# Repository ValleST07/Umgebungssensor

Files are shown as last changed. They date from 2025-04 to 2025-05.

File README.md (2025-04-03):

> [!IMPORTANT]
> Um ein Programm auf den ESP32-C3 zu flashen, muss in den bootloader-Mode gewechselt werden!\
> [Hier](https://www.edgemicrotech.com/esp32-c3-super-mini-arduino-ide-quick-start-guide/) ein einfaches Tutorial um den ESP32-C3 SuperMini richtig zu flashen.

# Umgebungssensor Projekt
## ESP32-C3 SuperMini
### Pin Out zum Board
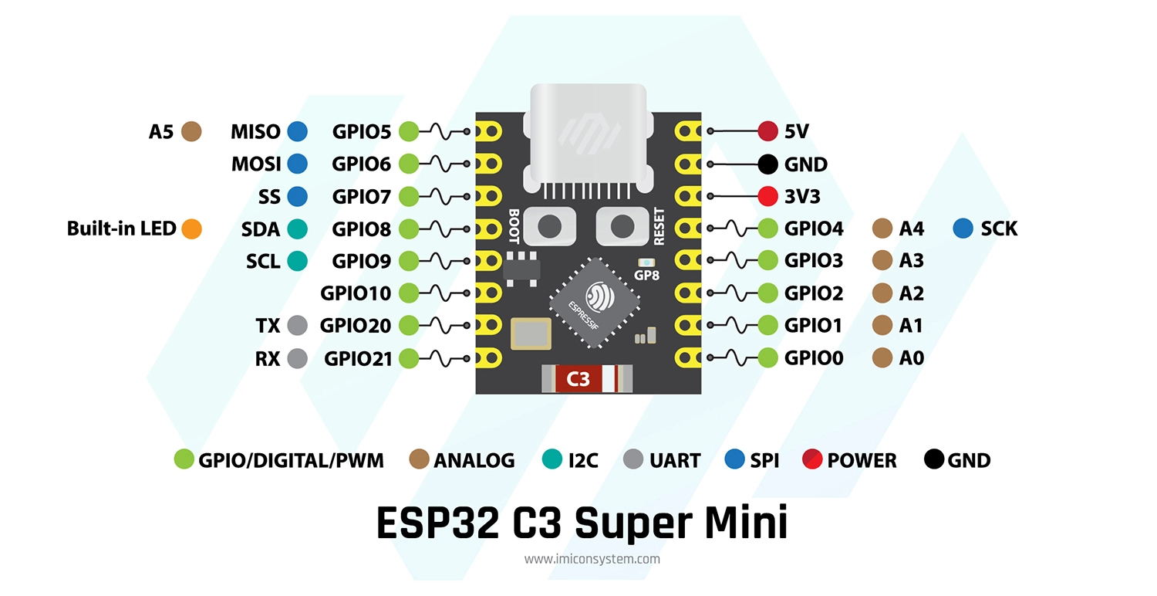
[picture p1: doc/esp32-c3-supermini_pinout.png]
ESP32-C3 SuperMini Pin Out

Wichtige PINs für das Projekt:
- GPIO8: I²C SDA
- GPIO9: I²C SCK
- GND: Ground Potential
- 3V3: 3,3V Potential für BME280 und SH1106
### Vorbereitung zur Programmierung ([ArduinoIDE](https://www.arduino.cc/en/software/))
- Wenn du bereits ESP32 programmiert hast, kannst du diesen Punkt überspringen!
    - Hier bitte noch den passenden Treiber herrunterladen: [CP210x USB to UART Bridge VCP Drivers](https://www.silabs.com/developer-tools/usb-to-uart-bridge-vcp-drivers?tab=downloads)
    - Im Board-Manager die ESP32 Boards installieren oder folgenden Link anführen: `https://dl.espressif.com/dl/package_esp32_index.json`
- Als Board zum Programmiern: ESP32C3 Dev Module

> [!NOTE]
> In der IDE in der Menubar unter "Tools" → "USB CDC on Boot" → "Enable" einstellen. Somit sollte später keine Probleme auftreten, wenn du die Serielleschnittstelle benutzen möchtest.

Somit sollten alle Vorbereitung zur Programmierung getroffen worden sein.

## Verdrahtung und PCB
### Verdrahtung
### PCB

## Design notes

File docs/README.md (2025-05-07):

![Made at CCA](https://img.shields.io/badge/Made_at-CCA-gray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)


> [!IMPORTANT]
> Um ein Programm auf den ESP32-C3 zu flashen, muss in den bootloader-Mode gewechselt werden!\
> [Hier](https://www.edgemicrotech.com/esp32-c3-super-mini-arduino-ide-quick-start-guide/) ein einfaches Tutorial um den ESP32-C3 SuperMini richtig zu flashen.

# Umgebungssensor Projekt
## ESP32-C3 SuperMini
### Pin Out zum Board
ESP32-C3 SuperMini Pin Out
Wichtige PINs für das Projekt:
- GPIO8: I²C SDA
- GPIO9: I²C SCK
- GND: Ground Potential
- 3V3: 3,3V Potential für BME280 und SH1106
### Vorbereitung zur Programmierung ([ArduinoIDE](https://www.arduino.cc/en/software/))
- Wenn du bereits ESP32 programmiert hast, kannst du diesen Punkt überspringen!
    - Hier bitte noch den passenden Treiber herrunterladen: [CP210x USB to UART Bridge VCP Drivers](https://www.silabs.com/developer-tools/usb-to-uart-bridge-vcp-drivers?tab=downloads)
    - Im Board-Manager die ESP32 Boards installieren oder folgenden Link anführen: `https://dl.espressif.com/dl/package_esp32_index.json`
- Als Board zum Programmiern: ESP32C3 Dev Module

> [!NOTE]
> In der IDE in der Menubar unter "Tools" → "USB CDC on Boot" → "Enable" einstellen. Somit sollte später keine Probleme auftreten, wenn du die Serielleschnittstelle benutzen möchtest.

Somit sollten alle Vorbereitung zur Programmierung getroffen worden sein.
## OLED-Display: SH1106
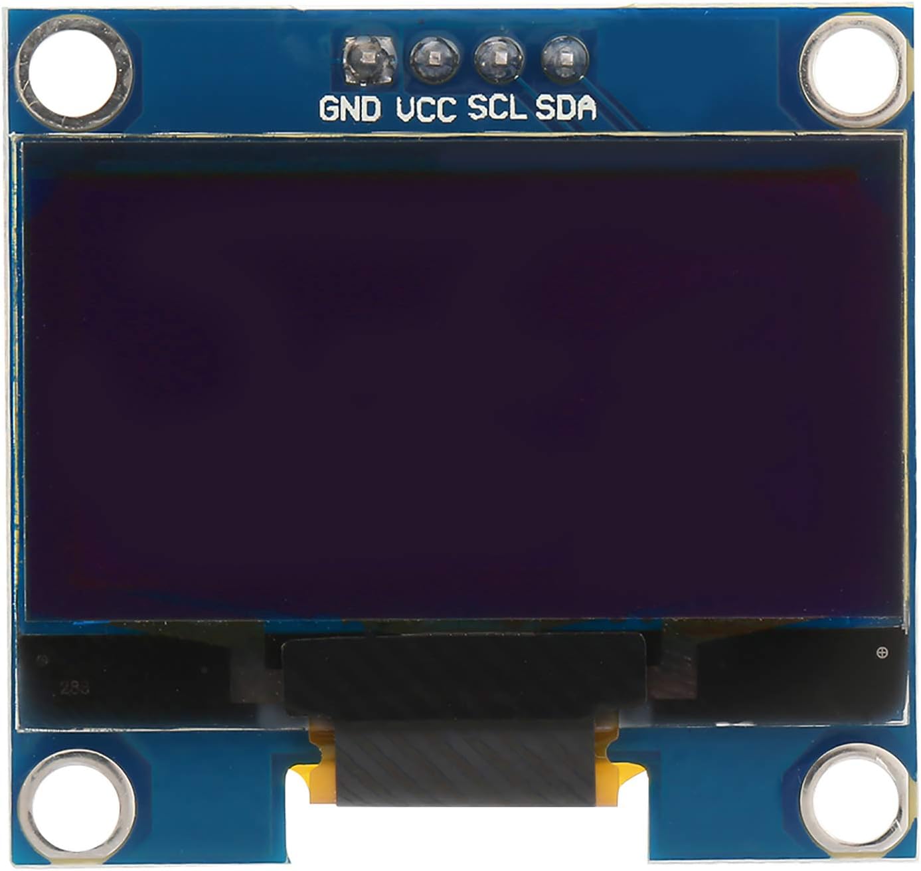
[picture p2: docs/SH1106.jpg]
 \
Das OLED Display kann über das Bussystem **I²C** angesteuert werden. Es aggiert dabei als Slave. Mithilfe der Library U8g2 wird die Anzeige angesteuert. Laut Datasheet kann es mit 3,3V oder 5V Versorgungsspannung bedient werden.<br/> <br/>
Weitere interessante Fakten:
- Dimensionen (LxBxT): 36 mm x 34 mm x 3 mm
- Auflösung: 128px x 64px
- Stromverbrauch: <11mA
- Displaygröße: 1,3 inch
- Displayfarbe: Monochrom (weiß)
## Sensor: BME280
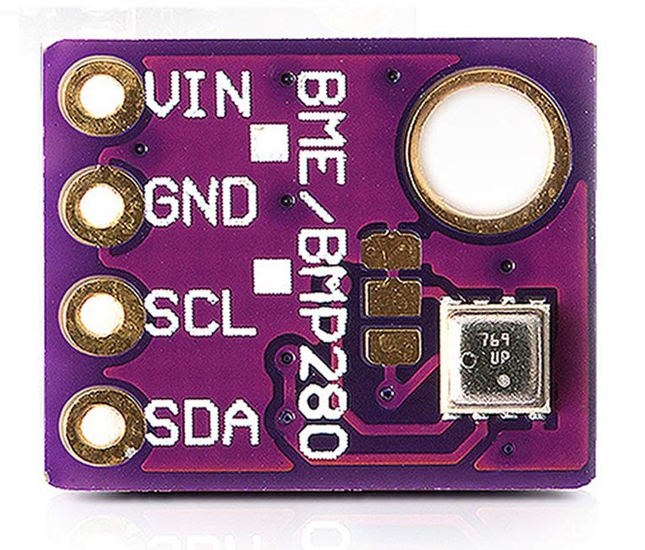
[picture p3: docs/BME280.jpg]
 \
Auch der Sensor wird via **I²C** angesteuert und befindet sich dabei ebenfalls im Slave-Modus. Die Softwareansteuerung erfolgte über die Adafruit BME280 Library die noch folgende Abhängigkeit mit der Adafruit Unified Sensor Driver hat. Auch dieses Modul kann mit 3,3V oder auch 5V betrieben werden, wie aus dem Datenblatt zu entnehemen ist.<br/> <br/>
Weitere interessante Fakten:
- Temperature: -40°C bis 85 °C;  Genauigkeit: ±1.0°C
- Luftdruck: 300 hPa bis 1100 hPa; Genauigkeit: ±1hPa
- Luftfeuchtigkeit: 0% bis 100%; Genauigkeit: ±3%
- Stromverbrauch: <1mA
## Verdrahtung und PCB
### Verdrahtung
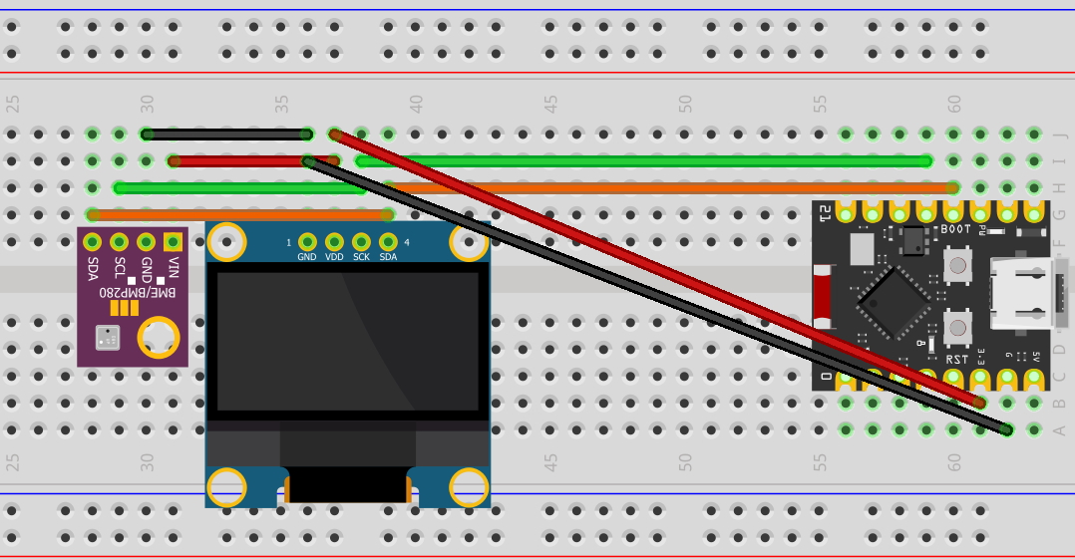
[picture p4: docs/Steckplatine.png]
Steckbrettaufbau

### PCB
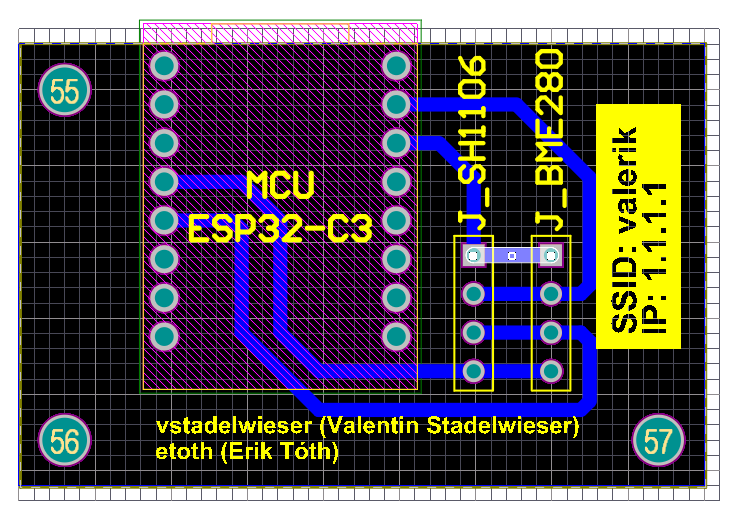
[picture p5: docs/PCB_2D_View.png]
2D-View: PCB

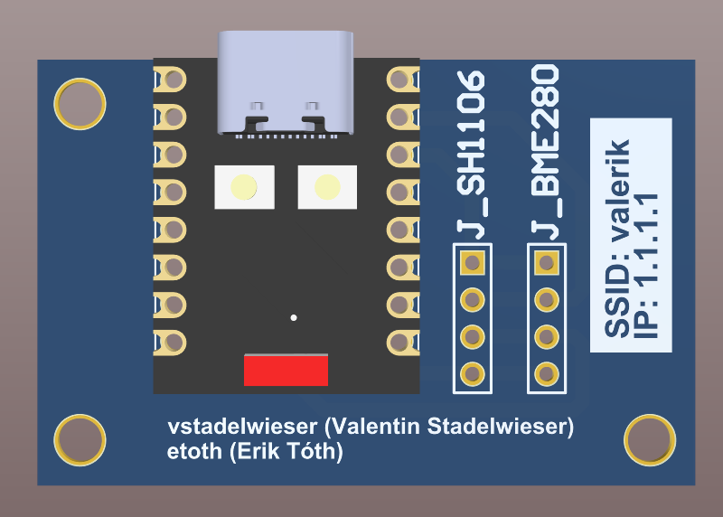
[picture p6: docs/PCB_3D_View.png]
3D-View: PCB


## Gehäuse
In Autodesk Inventor wurde ein simples und kompaktes Gehäusedesign vorgenommen.
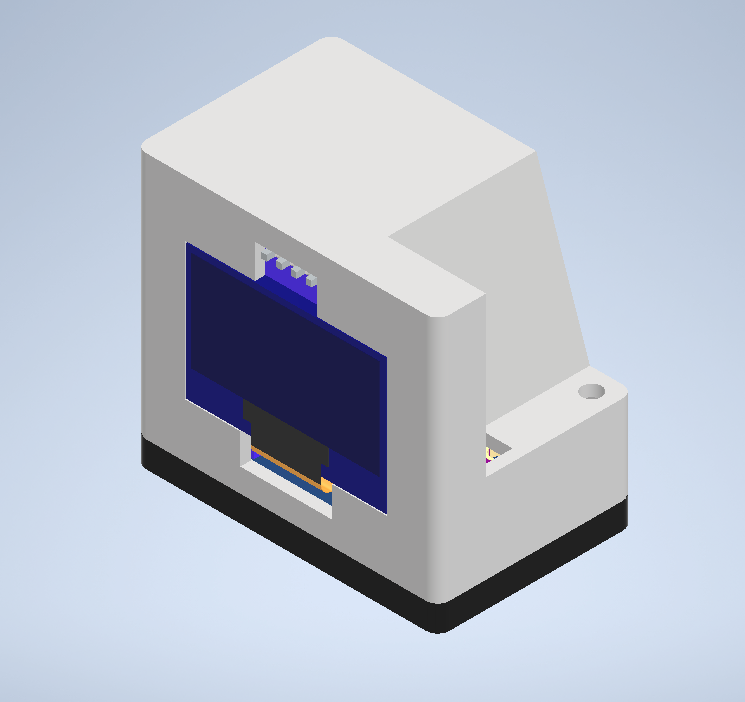
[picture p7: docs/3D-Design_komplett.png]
3D-Design: Komplett

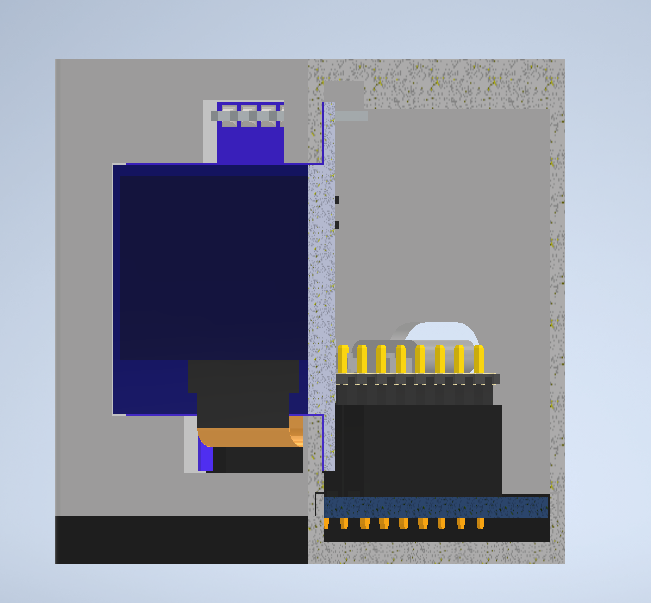
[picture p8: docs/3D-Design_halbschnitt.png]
3D-Design: Halbschnitt


## Website
### Funktionen
- Auswählbarer Internetmodus (Acces Point oder Standalone)
- OTA Update
- Graphische Aufbereitung mit Chart (nur im Standalone Mode)
- Display (Daten und Internet Einstellungen)
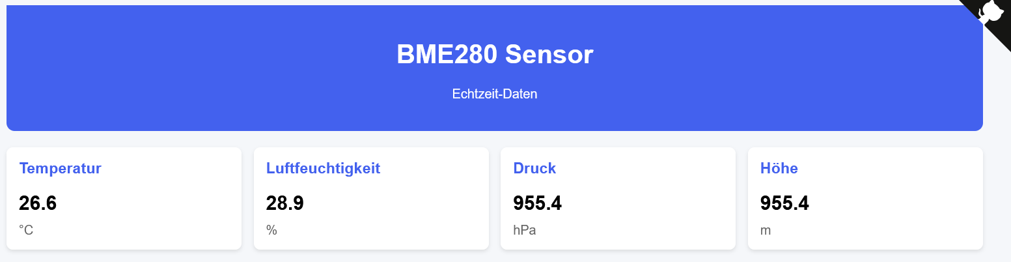
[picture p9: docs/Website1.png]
Website

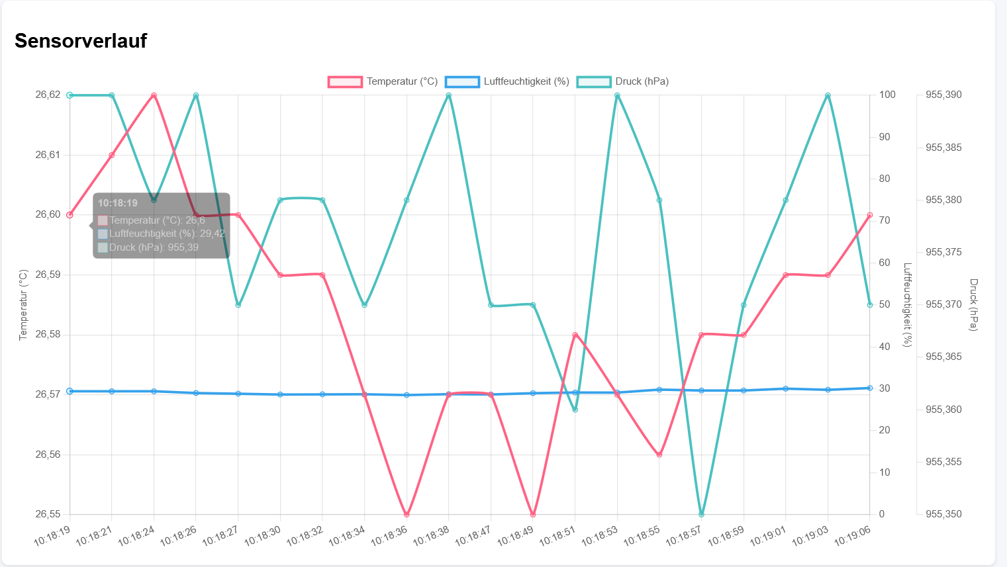
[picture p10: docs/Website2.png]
Website

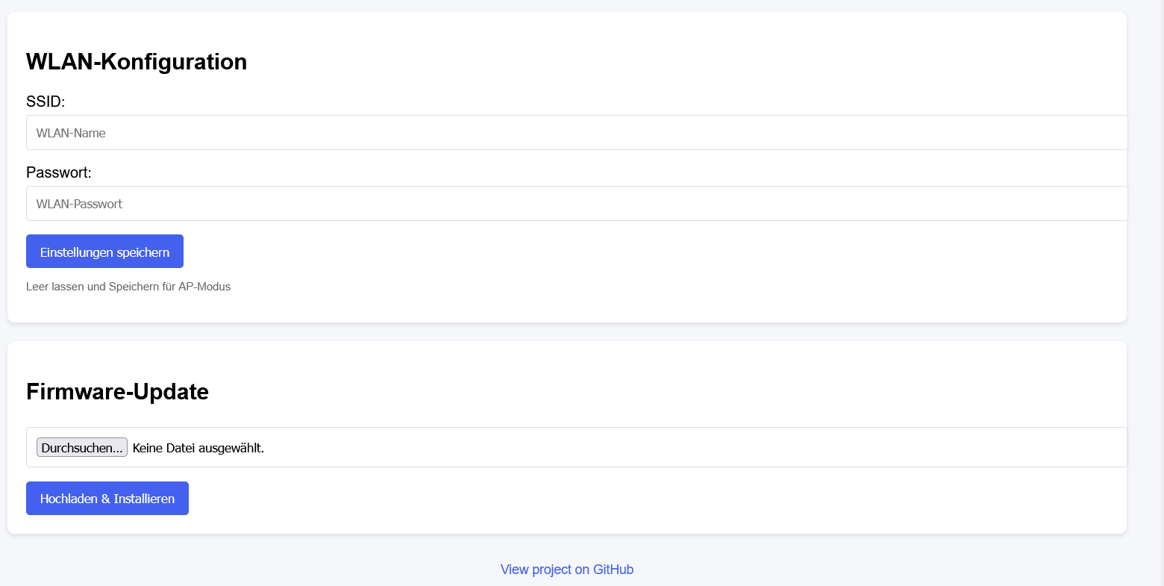
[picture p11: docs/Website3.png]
Website


## Fertig
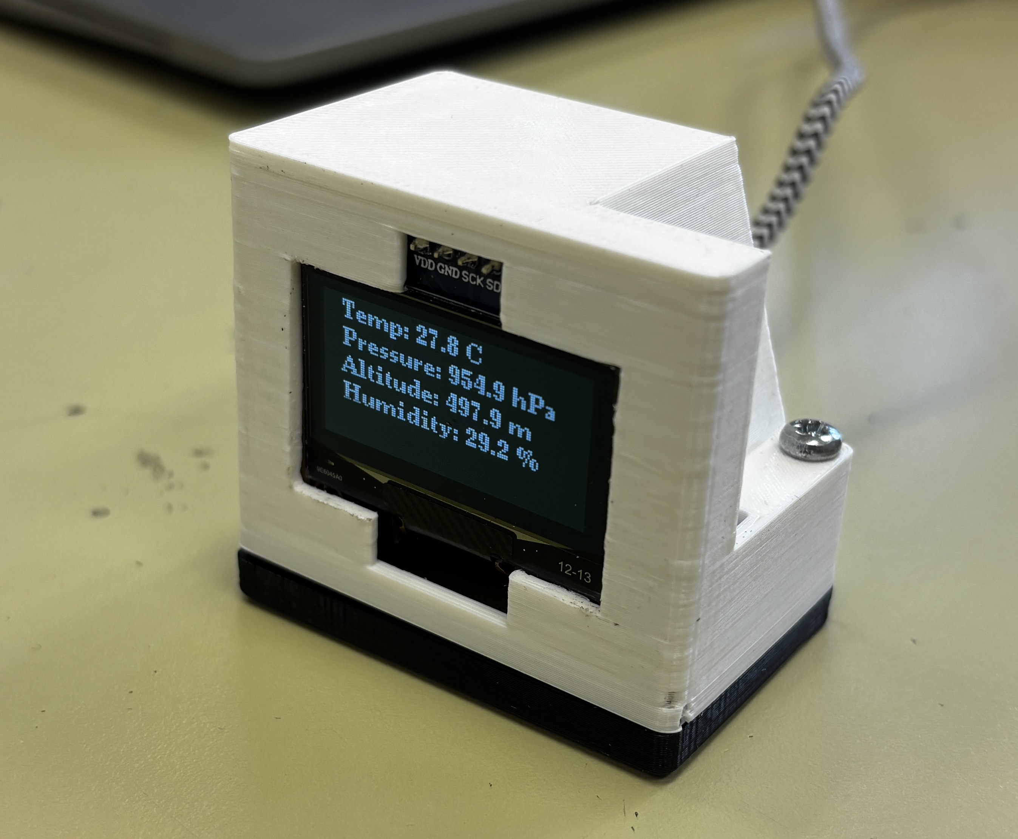
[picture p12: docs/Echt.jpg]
Echt


## Arbeitsteilung
Hardware & Gehäuse: Erik Tóth \
Software: Valentin Stadelwieser

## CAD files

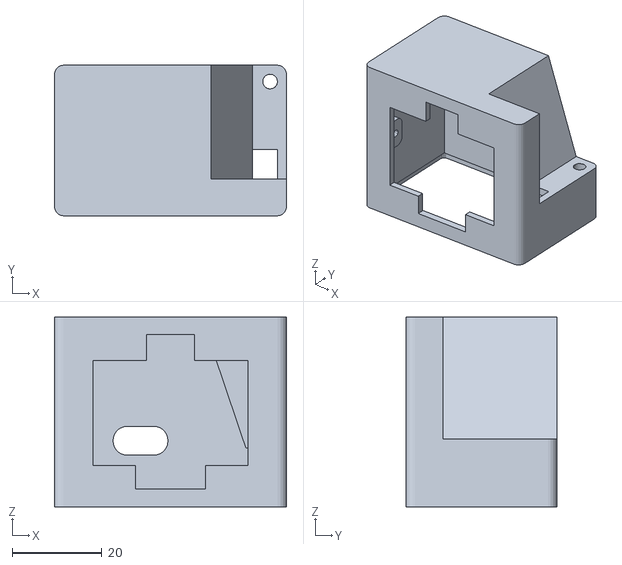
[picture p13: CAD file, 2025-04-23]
Fertigung/Gehaeuse_oben.stl
51.6 x 33.5 x 42.2

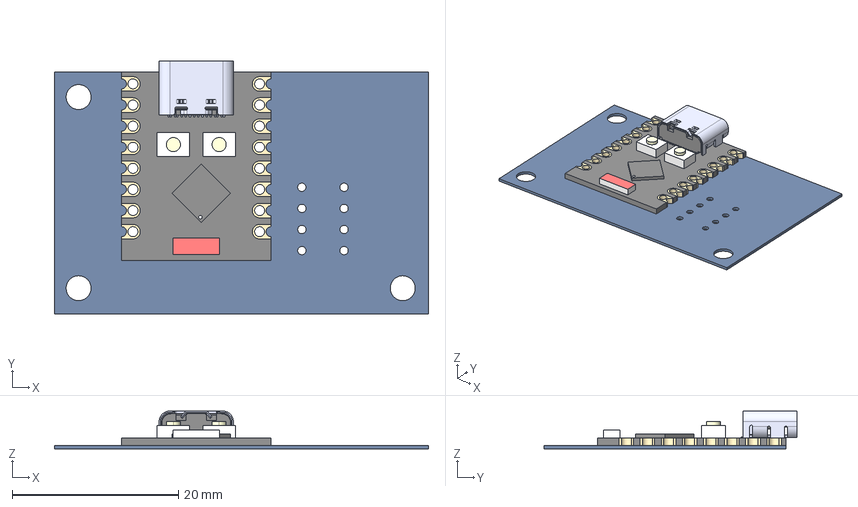
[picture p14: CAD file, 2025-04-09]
Umgebungssensor_PCB/Umgebungssensor_PCB.step
45.0 x 30.4 x 4.57 mm
Board c3mini
USB C
components (other)^ESP32-C3 SuperMini

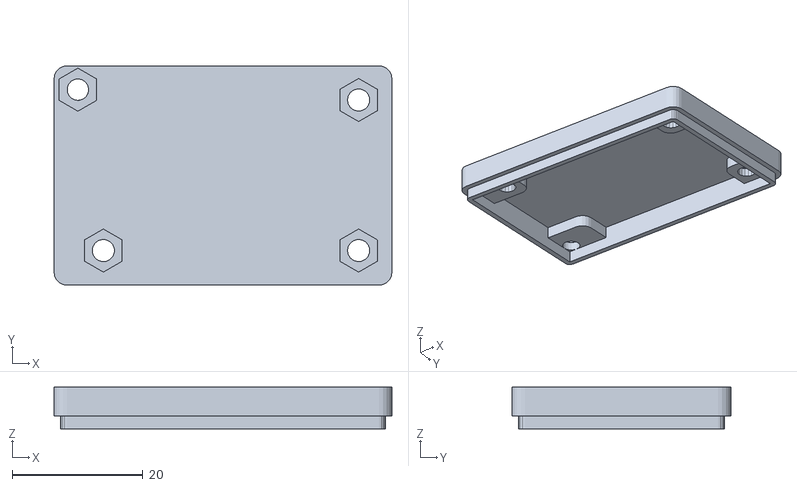
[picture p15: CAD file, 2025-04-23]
Fertigung/Gehaeuse_unten.stl
51.6 x 33.5 x 6.41

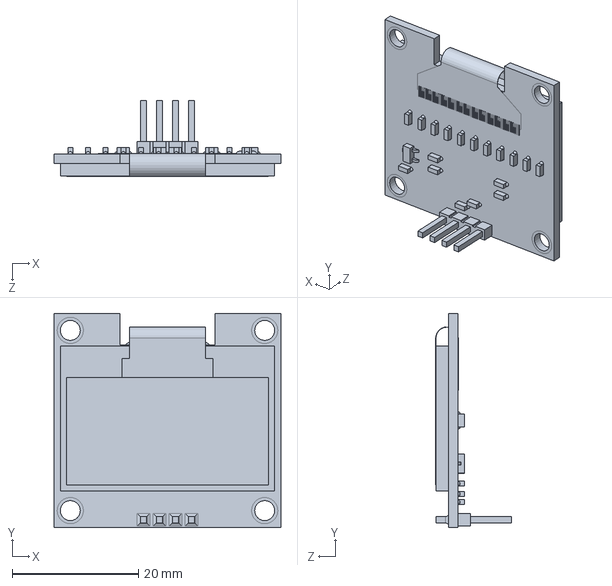
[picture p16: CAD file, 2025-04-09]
Gehaeuse_Umgebungssensor/Oled SH1106.SLDPRT
36.0 x 34.0 x 12.1 mm

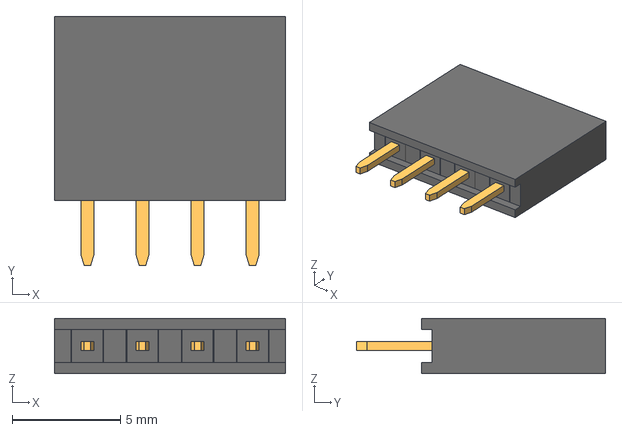
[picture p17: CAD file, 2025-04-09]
Gehaeuse_Umgebungssensor/zl262-4s_p2-54_l10-6_w2-54_h8-5.stp
10.7 x 11.5 x 2.54 mm

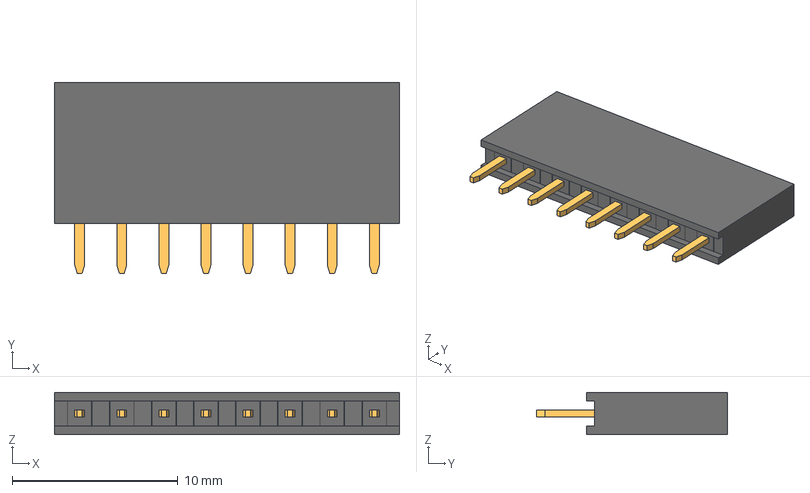
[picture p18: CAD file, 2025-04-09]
Gehaeuse_Umgebungssensor/zl262-8s_p2-54_l20-8_w2-54_h8-5.stp
20.8 x 11.5 x 2.54 mm

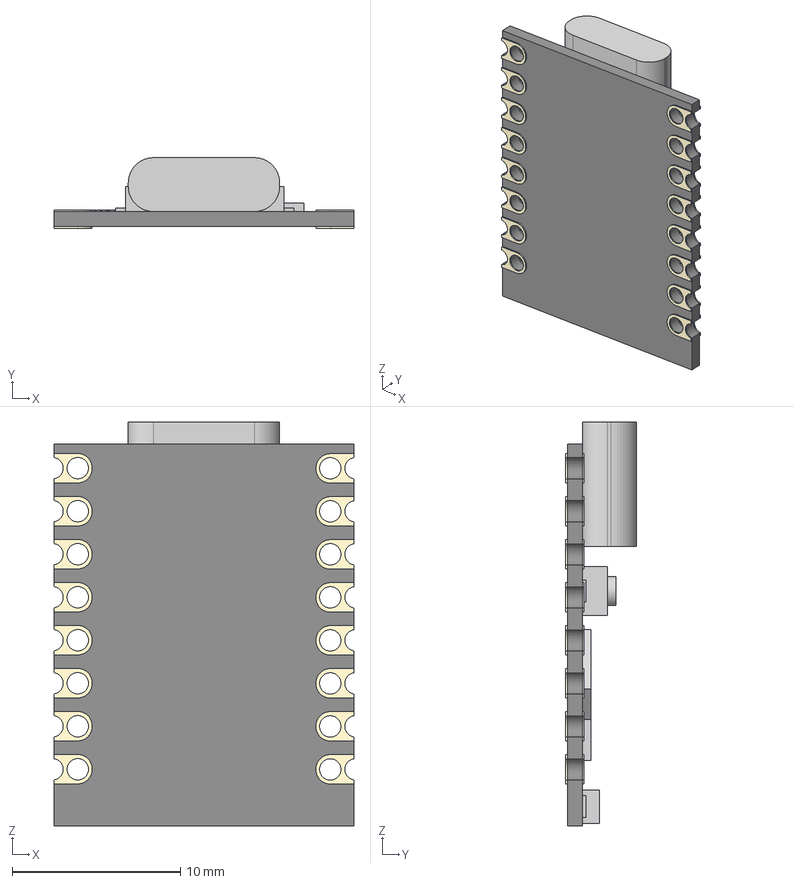
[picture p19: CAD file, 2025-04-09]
Gehaeuse_Umgebungssensor/ESP32-C3 supermini v5.step
17.8 x 4.20 x 24.0 mm

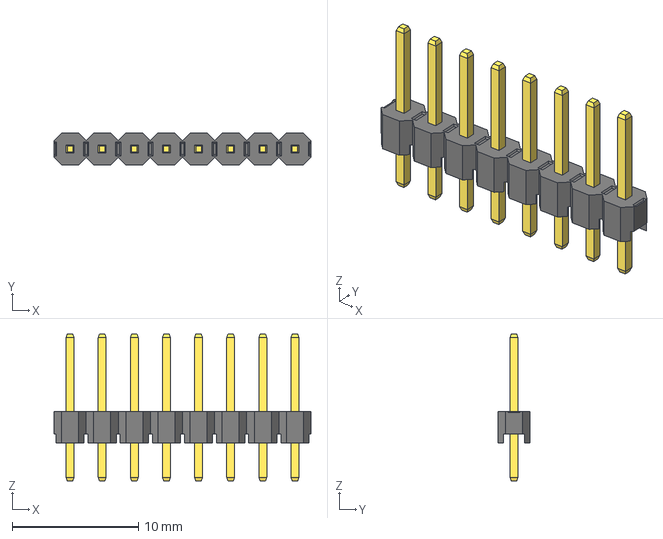
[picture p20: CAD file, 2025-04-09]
Gehaeuse_Umgebungssensor/PLS-8.step
20.3 x 2.54 x 11.6 mm

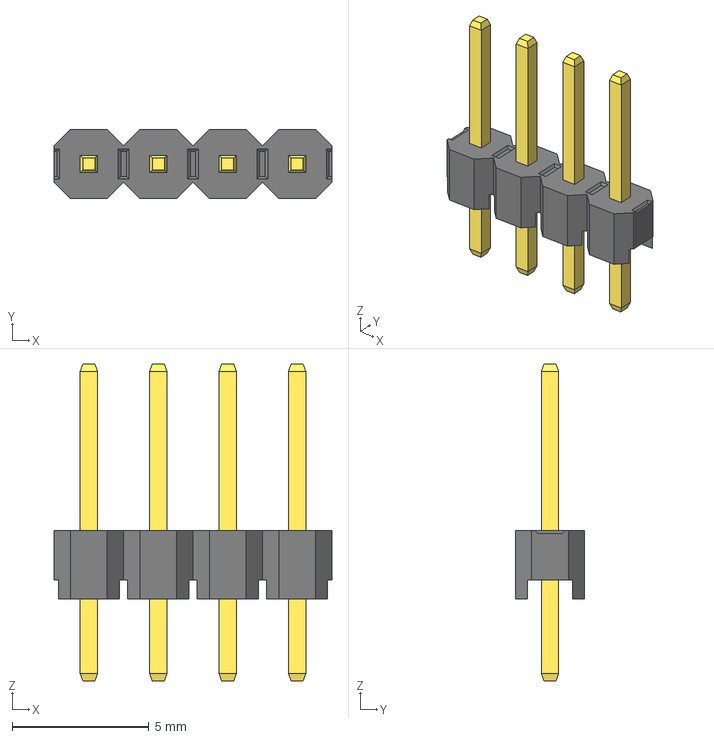
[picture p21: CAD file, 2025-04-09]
Gehaeuse_Umgebungssensor/PLS-4.step
10.2 x 2.54 x 11.6 mm

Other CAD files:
Gehaeuse_Umgebungssensor/Umgebungssensor_PCB.stl
Gehaeuse_Umgebungssensor/ESP32-C3 supermini v5/ESP32-C3 supermini v5.ipt
Gehaeuse_Umgebungssensor/GY-BME280/GY-BME280.ipt
Gehaeuse_Umgebungssensor/Gehaeuse_oben.ipt
Gehaeuse_Umgebungssensor/Gehaeuse_unten.ipt
Gehaeuse_Umgebungssensor/OldVersions/Gehaeuse_oben.0003.ipt
Gehaeuse_Umgebungssensor/OldVersions/Gehaeuse_unten.0003.ipt
Gehaeuse_Umgebungssensor/OldVersions/main.0006.iam
Gehaeuse_Umgebungssensor/Oled SH1106/Oled SH1106.ipt
Gehaeuse_Umgebungssensor/PLS-4/PLS-4.ipt
Gehaeuse_Umgebungssensor/PLS-8/PLS-8.ipt
Gehaeuse_Umgebungssensor/Umgebungssensor_PCB/OldVersions/Umgebungssensor_PCB.0002.ipt
Gehaeuse_Umgebungssensor/Umgebungssensor_PCB/Umgebungssensor_PCB.ipt
Gehaeuse_Umgebungssensor/main.iam
Gehaeuse_Umgebungssensor/zl262-4s_p2-54_l10-6_w2-54_h8-5/zl262-4s_p2-54_l10-6_w2-54_h8-5.ipt
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

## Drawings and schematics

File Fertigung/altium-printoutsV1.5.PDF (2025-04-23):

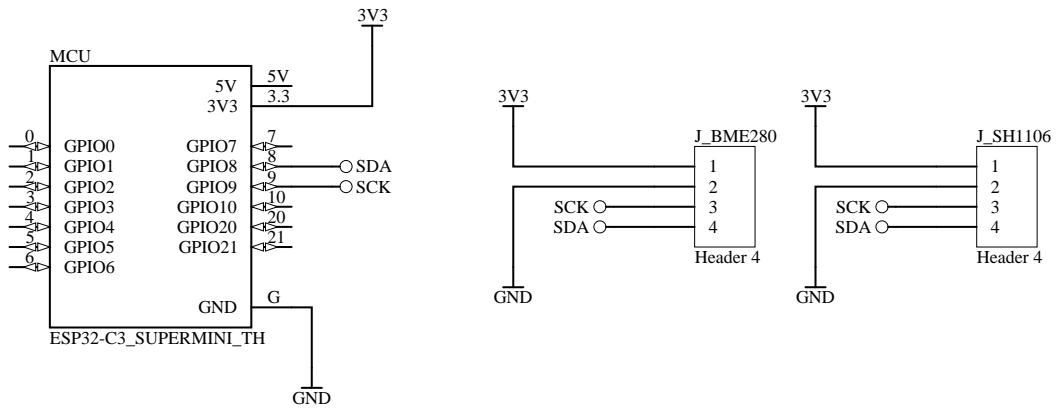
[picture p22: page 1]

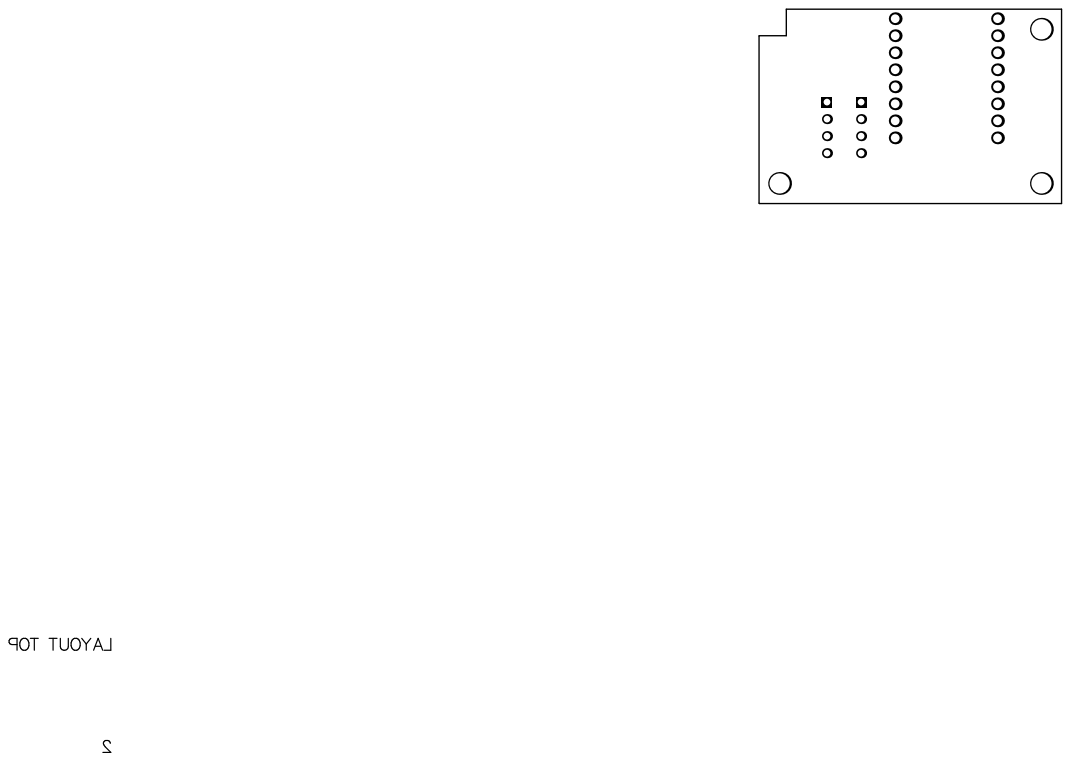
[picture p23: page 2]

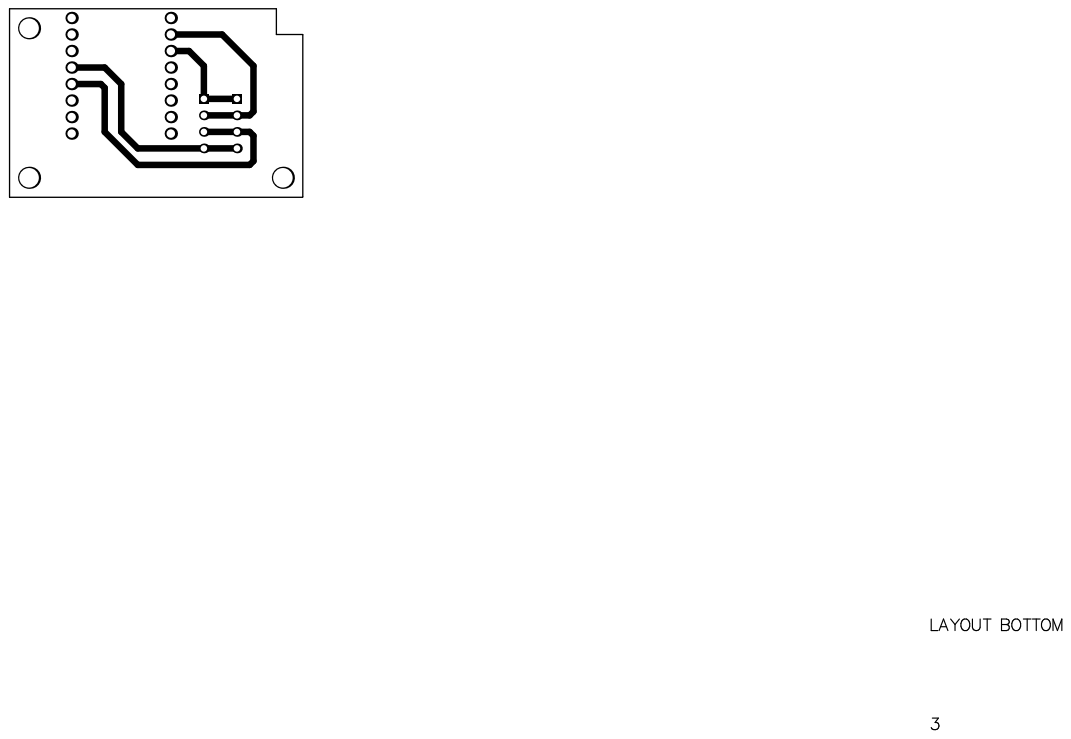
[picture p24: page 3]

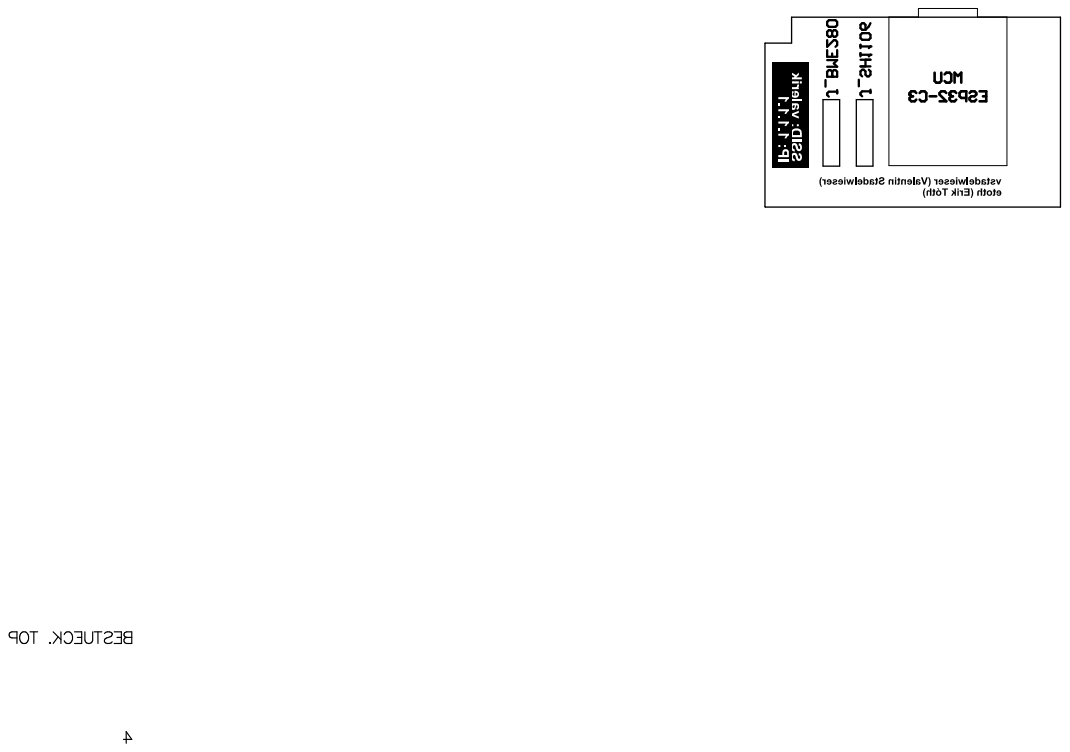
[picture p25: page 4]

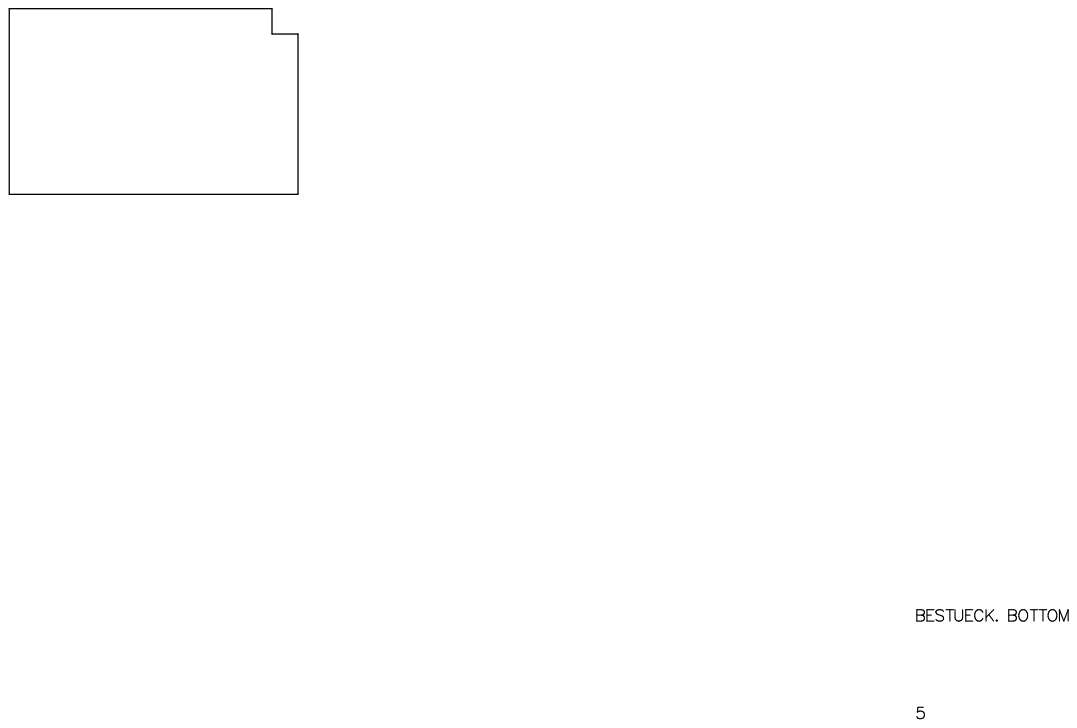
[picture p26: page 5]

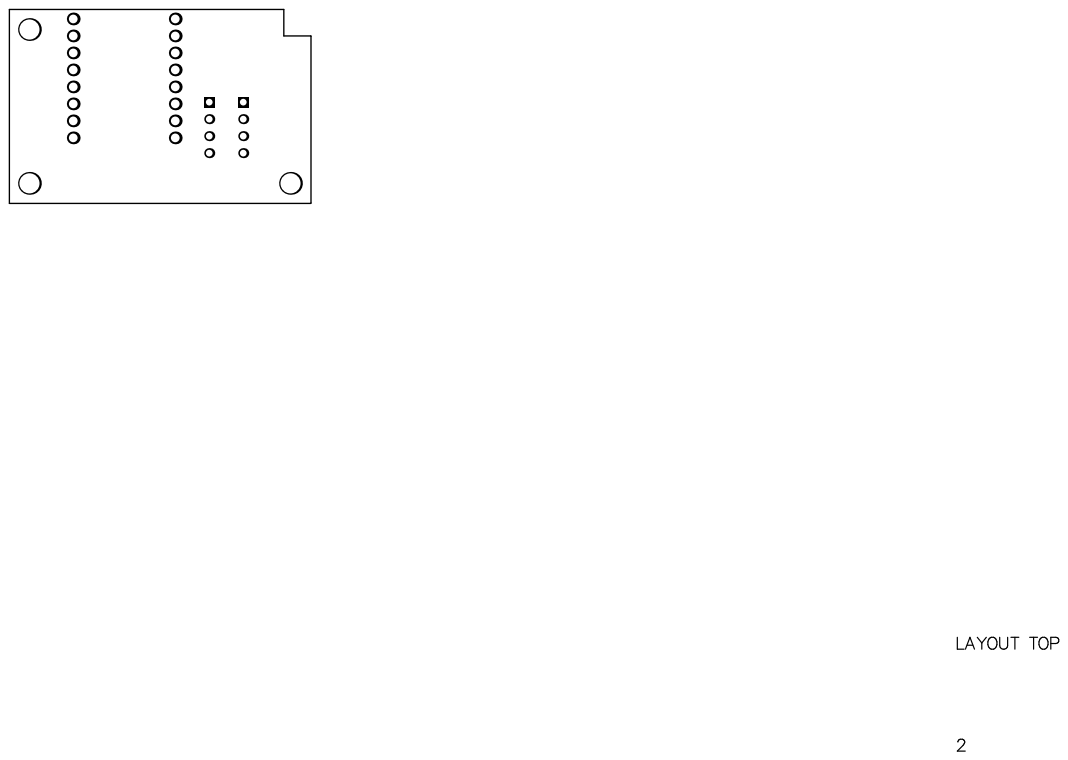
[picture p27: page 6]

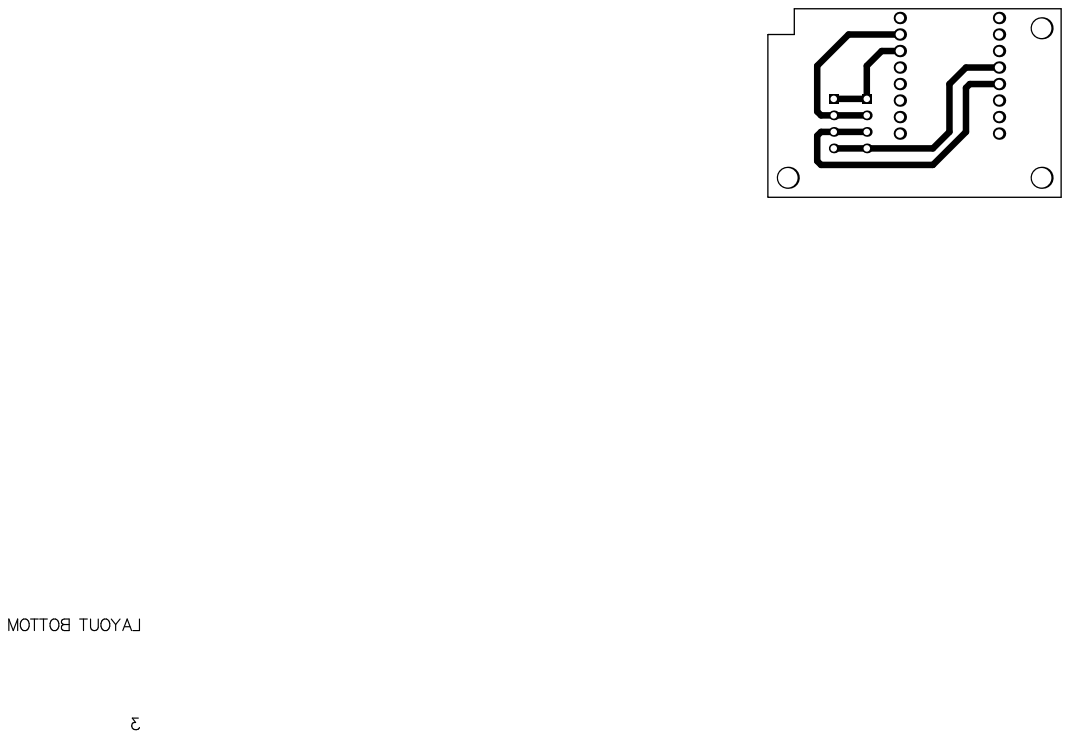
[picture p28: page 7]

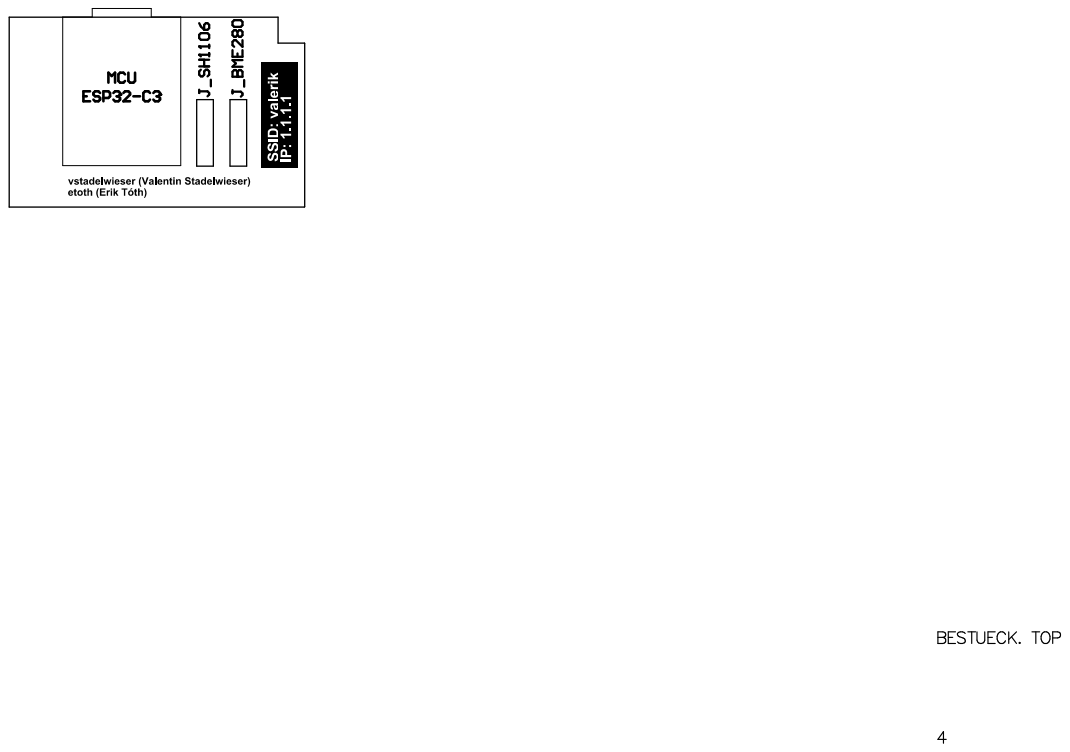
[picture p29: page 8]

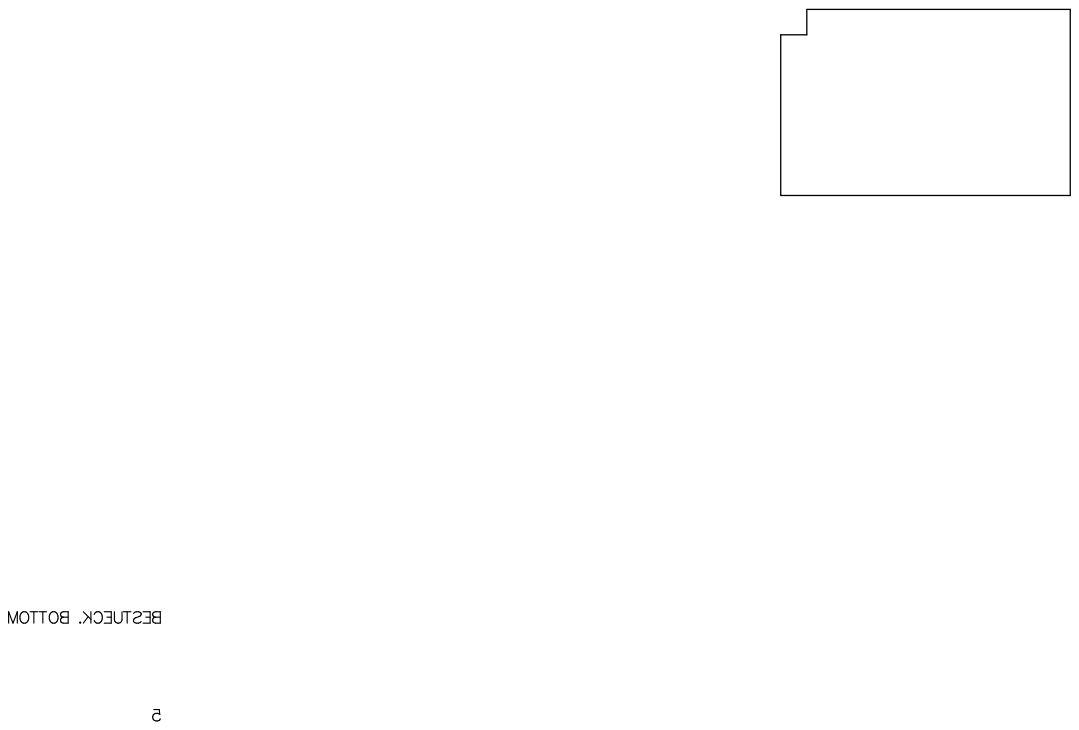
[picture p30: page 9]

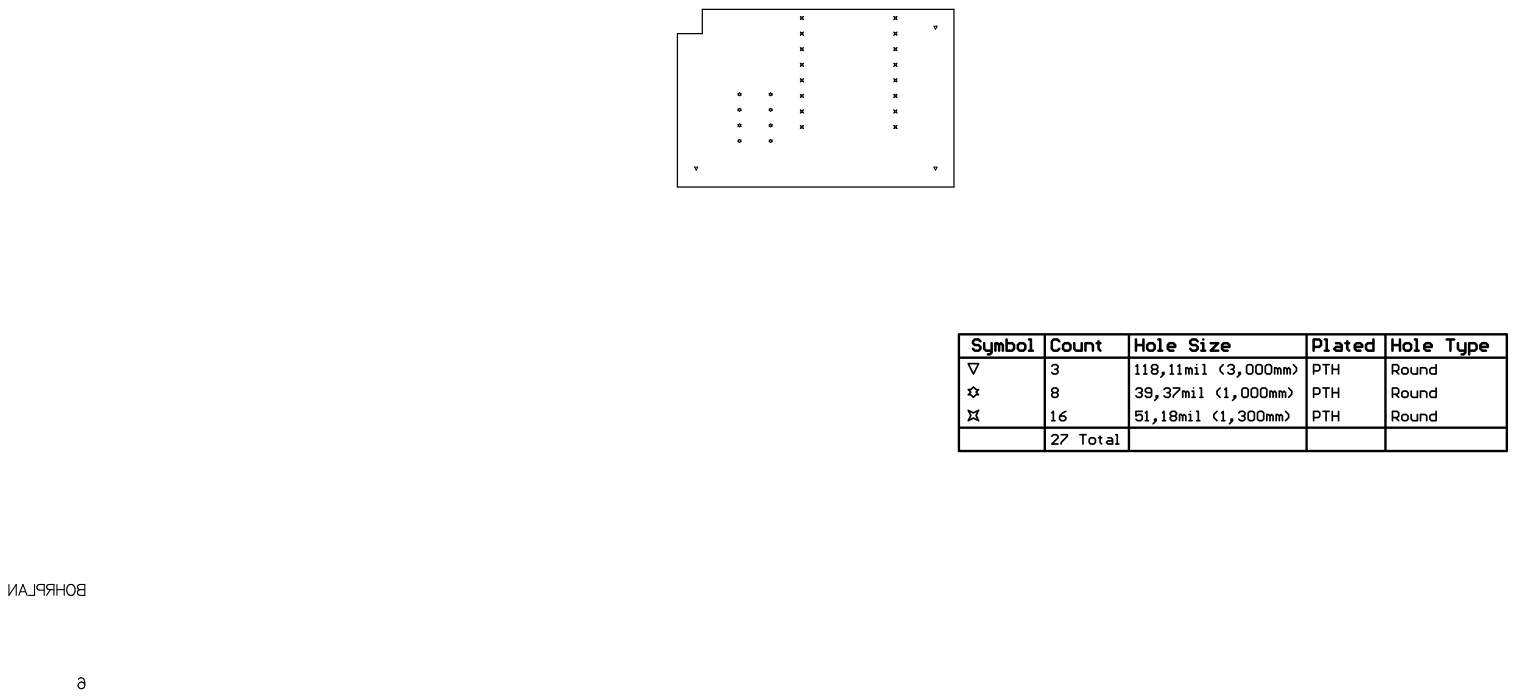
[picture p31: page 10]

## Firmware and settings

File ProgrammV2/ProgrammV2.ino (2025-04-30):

#include <Wire.h>
#include <Adafruit_Sensor.h>
#include <Adafruit_BME280.h>
#include <U8g2lib.h>
#include <WiFi.h>
#include <WebServer.h>
#include <Update.h>
#include <EEPROM.h>
#include "index.h"

#define EEPROM_SIZE 128
#define EEPROM_SSID_ADDR 0
#define EEPROM_PASS_ADDR 64
#define SEALEVELPRESSURE_HPA (1013.25)

// Forward Declaration
void server_init();
Adafruit_BME280 bme;
U8G2_SH1106_128X64_NONAME_F_HW_I2C display(U8G2_R0, /* reset=*/U8X8_PIN_NONE);

String html = String(MAIN_page);

const char ssid[10] = "valerik";
const char password[2] = "";
String WLANSSID = "";
String WLANPassword = "";
WebServer server(80);

bool isAP = true;

unsigned long delayTime;
unsigned long lastSwitch = 0;
bool showSensorData = true;

void saveWiFiCredentials(const String& ssid, const String& pass) {
  EEPROM.begin(EEPROM_SIZE);
  for (int i = 0; i < 32; ++i) {
    EEPROM.write(EEPROM_SSID_ADDR + i, i < ssid.length() ? ssid[i] : 0);
    EEPROM.write(EEPROM_PASS_ADDR + i, i < pass.length() ? pass[i] : 0);
  }
  EEPROM.commit();
  EEPROM.end();
}

void loadWiFiCredentials(String& ssid, String& pass) {
  EEPROM.begin(EEPROM_SIZE);
  char ssidBuff[33], passBuff[33];
  for (int i = 0; i < 32; ++i) {
    ssidBuff[i] = EEPROM.read(EEPROM_SSID_ADDR + i);
    passBuff[i] = EEPROM.read(EEPROM_PASS_ADDR + i);
  }
  ssidBuff[32] = 0;
  passBuff[32] = 0;
  ssid = String(ssidBuff);
  pass = String(passBuff);
  EEPROM.end();
}

void handleRoot() {
  server.send_P(200, "text/html", html.c_str());

}
void handleConfig() {
  if (server.method() == HTTP_POST) {
    WLANSSID = server.arg("ssid");
    WLANPassword = server.arg("password");
    Serial.println("Neues WLAN:");
    Serial.println(WLANSSID);
    Serial.println(WLANPassword);

    saveWiFiCredentials(WLANSSID, WLANPassword);
    // Stoppe Webserver, bevor WiFi-Modus geändert wird
    server.stop();

    // Wechsel vom Access Point zum Station-Modus
    WiFi.softAPdisconnect(true);
    WiFi.mode(WIFI_STA);

    WiFi.begin(WLANSSID.c_str(), WLANPassword.c_str());
    Serial.println("Verbinde mit neuem WLAN...");

    unsigned long startAttemptTime = millis();
    while (WiFi.status() != WL_CONNECTED && millis() - startAttemptTime < 30000) {
      delay(500);
      Serial.print(".");
    }

    if (WiFi.status() == WL_CONNECTED) {
      Serial.println("\n✅ Verbindung erfolgreich!");
      Serial.print("IP: ");
      Serial.println(WiFi.localIP());
      isAP = false;
    } else {
      Serial.println("\n❌ Verbindung fehlgeschlagen.");
      // Optional: wieder Access Point starten
      WiFi.mode(WIFI_AP);
      WiFi.softAP(ssid, password);
      WiFi.softAPConfig(IPAddress(1, 1, 1, 1), IPAddress(1, 1, 1, 1), IPAddress(255, 255, 255, 0));
      isAP = true;
    }

    // Server neu starten nach Moduswechsel
    server_init();
  } else {
    server.send(405, "text/plain", "Method Not Allowed");
  }
}
void handleData() {
  String json = "{";
  json += "\"temp\":" + String(bme.readTemperature()) + ",";
  json += "\"press\":" + String(bme.readPressure() / 100.0F) + ",";
  json += "\"alt\":" + String(bme.readAltitude(SEALEVELPRESSURE_HPA)) + ",";
  json += "\"hum\":" + String(bme.readHumidity());
  json += "}";
  server.send(200, "application/json", json);
}
void handleUpdate() {
  HTTPUpload& upload = server.upload();
  if (upload.status == UPLOAD_FILE_START) {
    Serial.printf("Update: %s\n", upload.filename.c_str());
    if (!Update.begin(UPDATE_SIZE_UNKNOWN)) {
      Serial.printf("Update Begin Error\n");
    }
  } else if (upload.status == UPLOAD_FILE_WRITE) {
    if (Update.write(upload.buf, upload.currentSize) != upload.currentSize) {
      Serial.printf("Update Write Error\n");
    }
  } else if (upload.status == UPLOAD_FILE_END) {
    if (Update.end(true)) {
      Serial.printf("Update Success\n");
    } else {
      Serial.printf("Update Failed\n");
    }
  }
  server.sendHeader("Connection", "close");
  server.send(200, "text/plain", (Update.hasError()) ? "FAIL" : "OK");
  delay(1000);
  ESP.restart();
}
void server_init() {
  server.on("/", handleRoot);
  server.on("/data", handleData);
  server.on(
    "/update", HTTP_POST, []() {
      server.send(200, "text/plain", "OK");
    },
    handleUpdate);
  server.on("/config", HTTP_POST, handleConfig);  // Handle the Wi-Fi configuration form submission
  server.begin();
  Serial.println("HTTP server started");
}
void setup() {
  Serial.begin(9600);
  while (!Serial)
    ;
  Serial.println(F("BME280 test"));

  display.begin();

  if (!bme.begin(0x76)) {
    Serial.println("Could not find a valid BME280 sensor, check wiring!");
    while (1) delay(10);
  }

  // Lade gespeicherte SSID & Passwort
  loadWiFiCredentials(WLANSSID, WLANPassword);
  Serial.println("Geladene WLAN-Daten:");
  Serial.println(WLANSSID);
  Serial.println(WLANPassword);

  if (WLANSSID.length() > 0) {
    WiFi.mode(WIFI_STA);
    WiFi.begin(WLANSSID.c_str(), WLANPassword.c_str());
    Serial.println("Versuche gespeicherte WLAN-Verbindung...");

    unsigned long startAttemptTime = millis();
    while (WiFi.status() != WL_CONNECTED && millis() - startAttemptTime < 10000) {
      delay(500);
      Serial.print(".");
    }

    if (WiFi.status() == WL_CONNECTED) {
      Serial.println("\n✅ Verbunden mit gespeichertem WLAN");
      Serial.print("IP: ");
      Serial.println(WiFi.localIP());
      isAP = false;
    }
  }

  // Falls nicht verbunden → Access Point starten
  if (WiFi.status() != WL_CONNECTED) {
    WiFi.mode(WIFI_AP);
    WiFi.softAP(ssid, password);
    WiFi.softAPConfig(IPAddress(1, 1, 1, 1), IPAddress(1, 1, 1, 1), IPAddress(255, 255, 255, 0));
    Serial.println("\nAccess Point gestartet");
    Serial.print("IP: ");
    Serial.println(WiFi.softAPIP());
    Serial.println(WiFi.softAPSSID());
    isAP = true;
  }

  server_init();

  delayTime = 1000;
  lastSwitch = millis();
}

void loop() {
  server.handleClient();
  //Display ab jetzt
  if (millis() - lastSwitch > (showSensorData ? 30000 : 5000)) {
    showSensorData = !showSensorData;
    lastSwitch = millis();
  }

  display.clearBuffer();
  display.setFont(u8g2_font_ncenB08_tr);

  if (showSensorData) {
    float temperature = bme.readTemperature();
    float pressure = bme.readPressure() / 100.0F;
    float altitude = bme.readAltitude(SEALEVELPRESSURE_HPA);
    float humidity = bme.readHumidity();

    display.setCursor(10, 10);
    display.print("Temp: ");
    display.print(temperature, 1);
    display.print(" °C");

    display.setCursor(10, 22);
    display.print("Pressure: ");
    display.print(pressure, 1);
    display.print(" hPa");

    display.setCursor(10, 34);
    display.print("Altitude: ");
    display.print(altitude, 1);
    display.print(" m");

    display.setCursor(10, 46);
    display.print("Humidity: ");
    display.print(humidity, 1);
    display.print(" %");

    display.setFont(u8g2_font_5x7_tr);  // Kleine Schrift für Fußzeile
    display.setCursor(40, 62);
    display.print("(c) VS&ET");

  } else {
    display.setFont(u8g2_font_ncenB08_tr);

    display.setCursor(30, 20);
    if (isAP) display.print("AP-Mode");
    else display.print("ST-Mode");

    display.setCursor(10, 34);
    if (isAP) {
      display.print("SSID: ");
      display.print(WiFi.softAPSSID());
    }

    display.setCursor(10, 46);
    display.print("IP: ");
    if (isAP) display.print(WiFi.softAPIP());
    else display.print(WiFi.localIP());

    display.setFont(u8g2_font_5x7_tr);
    display.setCursor(40, 62);
    display.print("(c) VS&ET");
  }

  display.sendBuffer();

  delay(delayTime);
}

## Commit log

2025-04-02 Altium PCB Design
    - Version: 1.0
    - PCB: Display & BME280 --> Header
    [Umgebungssensor_PCB.PcbDoc, Umgebungssensor_PCB.PrjPcb, Umgebungssensor_PCB.SchDoc]
2025-04-03 ReadME update
    [Umgebungssensor_PCB.PcbDoc]
2025-04-09 3D-Design start
    + PCB export as STP
    + Unten fertig
    [ESP32-C3 supermini v5.ipt, ESP32-C3 supermini v5.step, GY-BME280.ipt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]
2025-04-09 Programm AP und Client
2025-04-09 3D-Design Top
    + Fertig
    + TODO: Befestigung TOP <--> BOTTOM
    [Gehaeuse_oben.0002.ipt, Gehaeuse_oben.ipt, Oled SH1106.SLDPRT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]
2025-04-15 pushi pushi
    [Gehaeuse_oben.0002.ipt, Gehaeuse_oben.0003.ipt, Gehaeuse_oben.ipt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]
2025-04-23 Upload Fertigungsunterlagen
    [Gehaeuse_oben.stl, Gehaeuse_unten.stl, Umgebungssensor_PCB.PrjPcb]
2025-04-23 HTML auslagern und Char.js
2025-04-23 Update PCB Sch
    [Umgebungssensor_PCB.PrjPcb]
